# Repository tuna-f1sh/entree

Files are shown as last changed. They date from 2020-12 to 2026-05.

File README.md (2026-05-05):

# Entrée USB-C CAN Interface

The Entrée is a USB-C CAN/CAN FD (up to 5 Mbit/s) interface, designed to be fully feature-compatible with the [CANnectivity firmware](https://github.com/tuna-f1sh/cannectivity) firmware and Linux SocketCAN.

Entrée - like a Canapé but tastier...yes the logo is, and name was, Canapé but I didn't want to face a [Trademark](http://tmsearch.uspto.gov/bin/showfield?f=doc&state=4801:pgy4lj.2.5) dispute over an acute e for a hobby project...

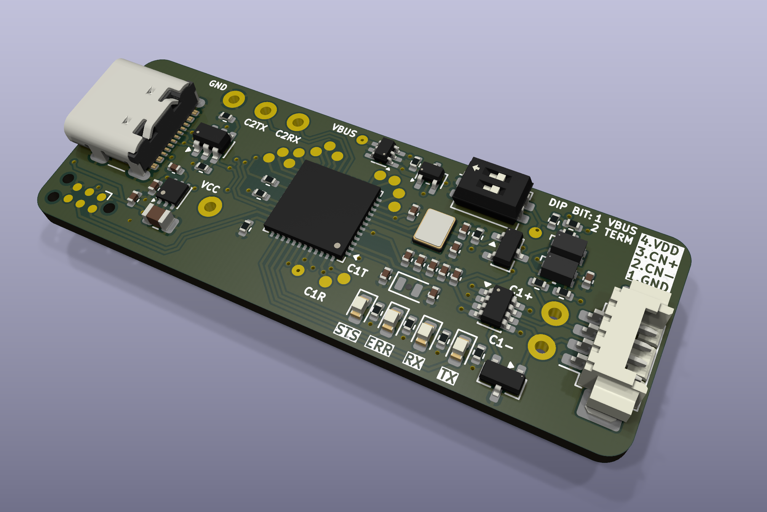
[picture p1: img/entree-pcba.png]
Entrée PCBA


## Features

* Compatiable with [CANnectivity firmware](https://github.com/tuna-f1sh/cannectivity); Zephyr based gs_usb.
* USB-C connection for use with modern hardware.
* Sotware and hardware switched control of 120 Ω termination resistor.
* Sotware and hardware switched control of VBUS to VDD connection for powering from USB.
* USB DFU and TagConnect 6-pin ISP for use as a development tool.
* FDCAN2 test points that with external transceiver can be used for a second CAN channel.
* USART test points for SLCAN without USB.
* Alternative JST SM04B (Qwiic/STEMMA) connector footprint for use with commonly available cables.
* Silkscreen art 🎨!
* [3d printed case](https://www.printables.com/model/681455-entree-usb-c-can-interface-case)

# Purchase

* [Tindie](https://www.tindie.com/products/22440/)

# Usage

> [!NOTE]
> The README has been updated for Entrée V2 which has a different hardware design to the original V1. The V1 supported candleLightFW and had USB-PD. The original V1 design is still available on the [V1 tag](https://github.com/tuna-f1sh/entree/commits/V1)

## Hardware Connection

The primary CAN connection is a [Molex Picoblade _53261-0471_](https://www.digikey.ch/products/en?keywords=WM7622CT-ND).

The connector was selected because they are commonly used on Drones and so Picoblade to 0.1" header cables can also be easily obtained:

* [1 Bit Sqaured Black Magic 0.1" female cable](https://1bitsquared.com/products/black-magic-01in-pin-header-serial-cable).

Alternatively, one can obtain [pre-crimped female cable assemblies _15134-0402_](https://www.digikey.ch/product-detail/en/molex/0151340402/WM15258-ND/6198148) or [female 4-pin housing _51021-04_](https://www.digikey.ch/product-detail/en/molex/0510210400/WM1722-ND/242844) for custom cabling.

A secondary unfitted [_JST SM04B_](https://www.digikey.ch/products/en?keywords=455-1804-1-ND) (otherwise known as Qwiic/STEMMA) footprint is available on the bottom of the board if one wishes to use those [commonly available cables](https://www.adafruit.com/category/619) instead. JST pre-crimped part is _A04SR04SR30K152A_.

### Wiring Example

Below is a wiring example showing the Entrée Picoblade and JST pinout. A Black Magic 0.1" female header cable is connected to the Picoblade and standard STEMMA QT connected to the secondary JST header. **Note both cable colouring is non-standard due to optimal board layout**.

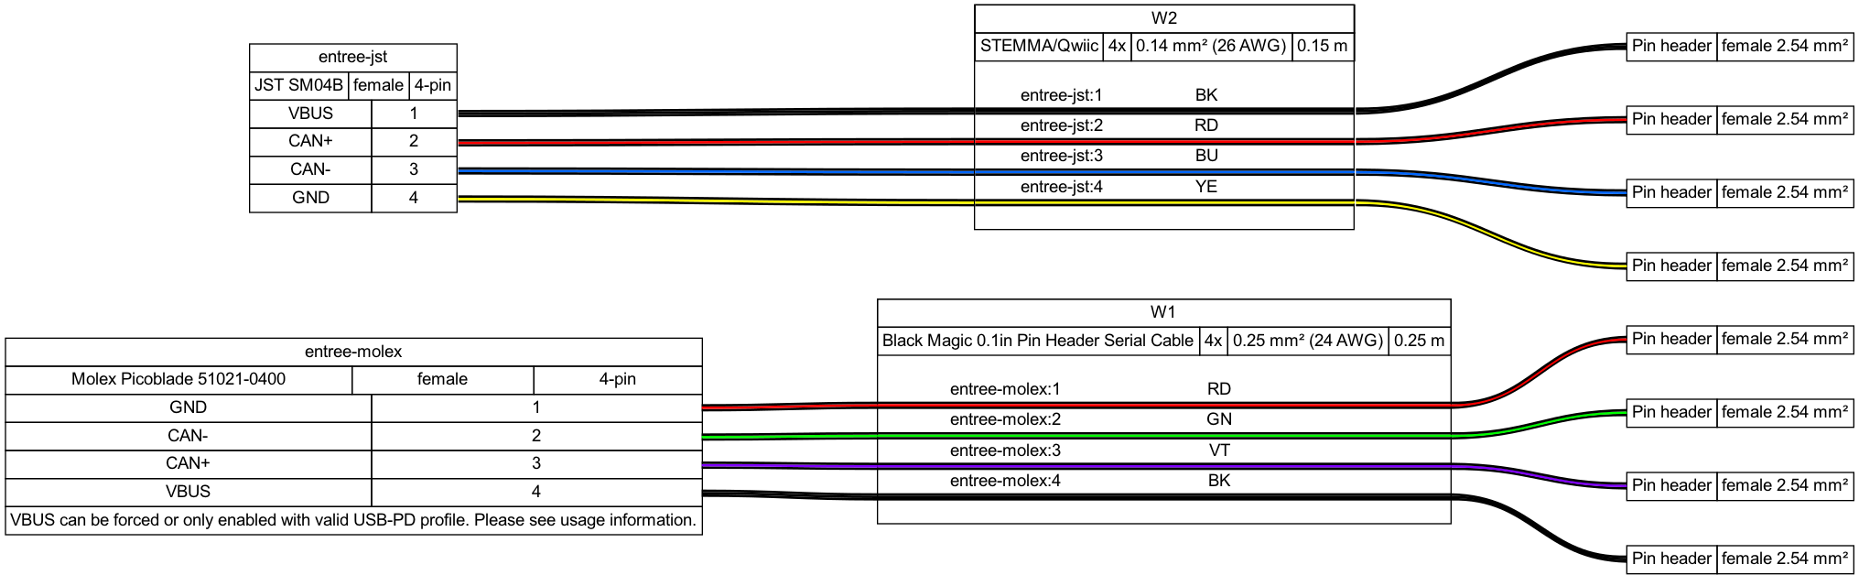
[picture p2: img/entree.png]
Entrée wiring diagram


## Software

A [Vagrant](https://www.vagrantup.com/) virtual machine environment is provided in the ./linux-vm folder for those on non-Linux hosts or who want a pre-configured environment. Install Vagrant and VirtualBox and then setup the machine from within the ./linux-vm folder with the `vagrant up` command.

### Linux SocketCAN

Entrée comes with _CANnectivity_ firmware which is intended for use with a Linux host. Most Linux distributions include the gs_usb driver and can kernel modules by default so getting started is very easy.

The below assume a single CAN interface is present with default name `can0` - if multiple interfaces are present then the name may be different and can be found with `ip link`.

#### Create CAN network interface [[ref]](https://elinux.org/Bringing_CAN_interface_up)

```
sudo ip link set can0 type can bitrate BIT_RATE # where BIT_RATE is the CAN bus speed in b/s
sudo ip link set up can0
```

#### Control Termination Resistor

```
sudo ip link set dev can0 type can termination 0  # Disable termination resistor on can0
sudo ip link set dev can0 type can termination 120 # Enable 120 ohm termination resistor on can0
```

#### Print Interface Help

```
ip link set can0 type can help
ip -details -statistics link show can0 # Show detailed information about can0 including termination resistor status
```

#### CLI

Install `can-utils` using one's package manager and then various command line tools are available.

```
cansend can0 999#DEADBEEF   # Send a frame to 0x999 with payload 0xdeadbeef
candump can0                # Show all traffic received by can0
canbusload can0 500000      # Calculate bus loading percentage on can0
cansniffer can0             # Display top-style view of can traffic
cangen can0 -D 11223344DEADBEEF -L 8    # Generate fixed-data CAN messages
```

See the [can-utils README](https://github.com/linux-can/can-utils/blob/master/README.md) for more.

#### Cangaroo GUI

The Cangaroo GUI can be compiled for Linux hosts. See [Cangaroo](https://github.com/normaldotcom/cangaroo/).

### Windows

To use the default firmware on Windows, one can use [Cangaroo](https://github.com/normaldotcom/cangaroo/): [Pre-compiled Win32 binary](https://www.dropbox.com/s/dyh9gvt572v8nhn/cangaroo-win32-0363ce7.zip?dl=0).

Alternatively, to use [SocketCAN](#linux-socketcan) one can use the pre-configured virtual machine explained at the start of the [Software section](#software).

### Python

The [python-can](https://python-can.readthedocs.io/en/master/#) module supports 'socketcan' (Linux host) and 'gs_usb' interfaces so options for all hosts are covered - see the [configuration page](https://python-can.readthedocs.io/en/master/configuration.html).

Paired with the [cantools](https://pypi.org/project/cantools/) module, one has access to powerful CLI tools and scripting for CAN bus operations including use with database definition files.

Both modules are pre-installed in the Vagrant virtual machine.

## DIP Switches

> [!NOTE]
> The DIP switches override software control.

| Switch | Decimal | Set Action |
|---|---|---|
| 1 | 1 | Enable VBUS -> VDD. |
| 2 | 2 | Enable 120 ohm CAN\_H/CAN\_L termination resistor |

---

[JBR Engineering Research Ltd](https://jbrengineering.co.uk)

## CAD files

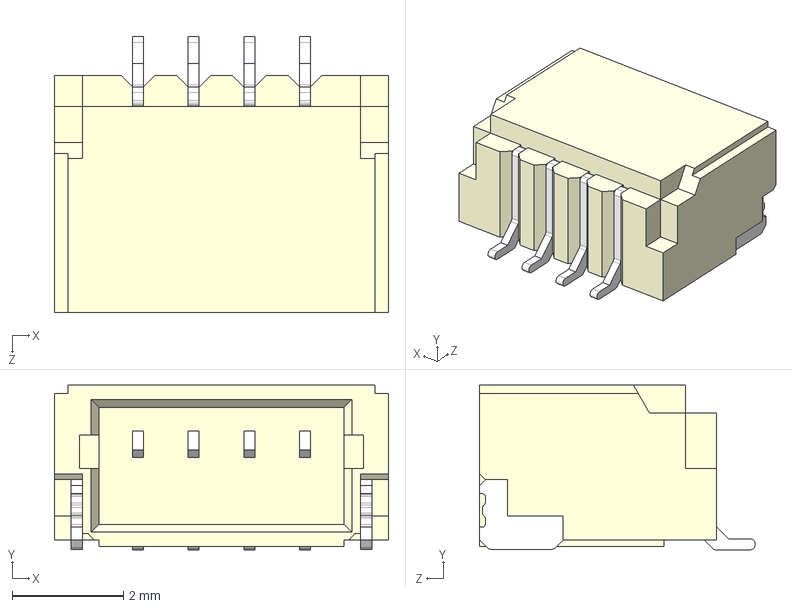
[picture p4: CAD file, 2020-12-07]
models/SM04B-SRSS-TB(LF)(SN)--3DModel-STEP-56544.STEP
6.00 x 2.96 x 4.95 mm

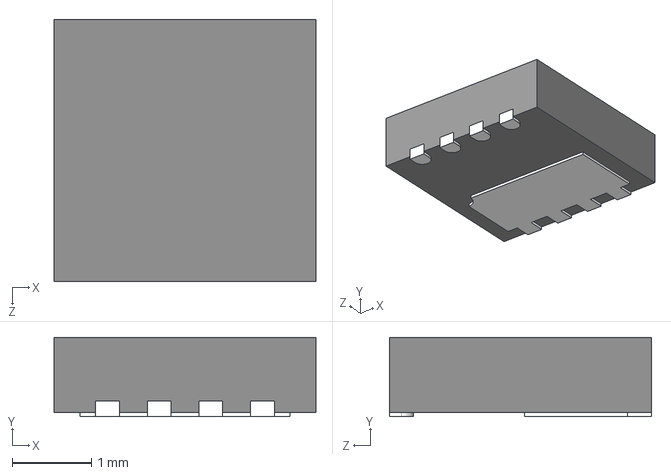
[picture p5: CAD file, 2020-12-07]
models/STL3N65M2--3DModel-STEP-56544.STEP
3.30 x 1 x 3.30 mm

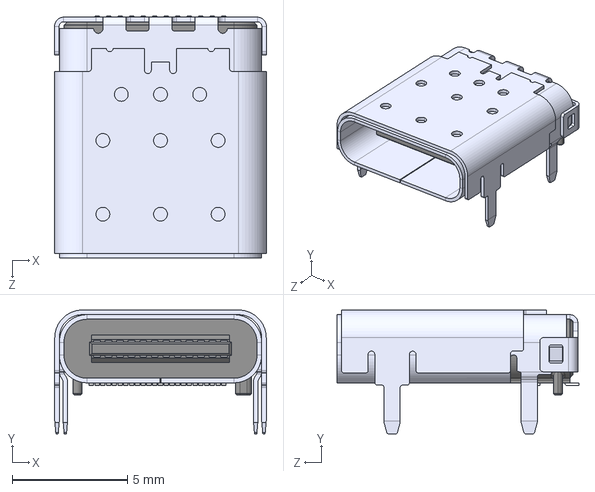
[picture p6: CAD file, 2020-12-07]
models/12401598E4#2A.STEP
9.20 x 5.38 x 10.5 mm

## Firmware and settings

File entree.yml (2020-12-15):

templates: # defining templates to be used later on
  - &molex_pico_f
    type: Molex Picoblade 51021-0400
    subtype: female
  - &molex_pico_m
    type: Molex Picoblade 53261-0471
    subtype: male
  - &bmp_wire
    gauge: 0.25 mm2
    colors: [RD, GN, VT, BK]
  - &qwiic_wire
    gauge: 0.14 mm2
    colors: [BK, RD, BU, YE]

connectors:
  entree-molex:
    <<: *molex_pico_f
    pinlabels: [GND, CAN-, CAN+, VBUS]
    notes: VBUS can be forced or only enabled with valid USB-PD profile. Please see usage information.
  header:
    style: simple
    autogenerate: true
    type: Pin header
    subtype: female 2.54 mm²
  entree-jst:
    type: JST SM04B
    subtype: female
    pinlabels: [VBUS, CAN+, CAN-, GND]

cables:
  W1:
    <<: *bmp_wire
    type: Black Magic 0.1in Pin Header Serial Cable
    show_equiv: true # auto-calculate AWG equivalent
    length: 0.25
  W2:
    <<: *qwiic_wire
    type: STEMMA/Qwiic
    show_equiv: true # auto-calculate AWG equivalent
    length: 0.150

connections:
  -
    - entree-molex: [1,2,3,4]
    - W1: [1,2,3,4]
    - header
  -
    - entree-jst: [1,2,3,4]
    - W2: [1,2,3,4]
    - header

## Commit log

2020-12-07 schematic capture and layout complete
    [12401598E4#2A.STEP, STL3N65M2--3DModel-STEP-56544.STEP, canape.kicad_pcb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]
2020-12-07 add JST not-fitted on underside
    [canape.kicad_pcb, canape.sch]
2020-12-07 R0 PCB to fab
    [SM04B-SRSS-TB(LF)(SN)--3DModel-STEP-56544.STEP, canape.kicad_pcb, canape.sch]
2020-12-11 README, Vagrant env and bins
    [canape.kicad_pcb, canape.sch]
2020-12-15 project rename from Canapé to Entreé
    [entree.kicad_pcb, entree.sch]
2021-02-14 pcan_cantact firmware link to upstream now merged
    [entree.sch]
2022-01-05 correct typo
    [entree.kicad_pcb, entree.sch]
2023-01-09 replace logo for pcb backside and make smaller
2023-03-09 Migration to 7.0 and github action
    release path of workflow
    two workflows
    nousbpd variant
    clean workflows
    [entree.kicad_pcb, entree.kicad_sch, entree.sch]
2023-03-09 add ESD diode to CAN; 3V3 LDO available and upto 20V; tidy layout
    [entree.kicad_pcb, entree.kicad_sch]
2023-03-09 include boarders in pdf print
2023-03-12 fix unconnected vcc; move 3v3 label silkscreen
    [entree.kicad_pcb]
2023-12-11 correct USB TVS datasheet
    [entree.kicad_sch]
2023-12-15 add link to 3d printed case
2024-02-26 updates for KiCad 8.0
    [entree.kicad_pcb, entree.kicad_sch]
2025-06-30 gpio swtich termination resistor support
    [entree.kicad_pcb, entree.kicad_sch]
2026-01-18 wip: updating to support CANnectivity
    [entree.kicad_pcb, entree.kicad_sch]
2026-01-20 update labels to global
    [entree.kicad_pcb, entree.kicad_sch]
2026-01-20 pre layout
    [entree.kicad_pcb, entree.kicad_sch]
2026-01-27 layout tweaks
    [entree.kicad_pcb, entree.kicad_sch]
2026-01-30 layout first pass complete
    [entree.kicad_pcb, entree.kicad_sch]
2026-02-01 layout v2
    [entree.kicad_pcb, entree.kicad_sch]
2026-02-02 th test points
    [entree.kicad_pcb, entree.kicad_sch]
2026-02-02 change usb-c fp, jlcpcb parts
    [entree.kicad_pcb, entree.kicad_sch]
2026-02-16 fix 3v3 ldo part number not specified
    [entree.kicad_pcb, entree.kicad_sch]
2026-02-24 vdd -> vbus diode protect
    [entree.kicad_pcb, entree.kicad_sch]
2026-03-03 mcuboot jumper
    [entree.kicad_pcb, entree.kicad_sch]
2026-03-20 update CANnectivity links to fork for entree board
2026-05-05 README: TCAN33xG is upto 5 Mbit/s not 8
    [entree.kicad_sch]
2026-05-05 note on alternative TCAN3414DDFR for 8 Mbit/s CANFD support
    [entree.kicad_pcb, entree.kicad_sch]
